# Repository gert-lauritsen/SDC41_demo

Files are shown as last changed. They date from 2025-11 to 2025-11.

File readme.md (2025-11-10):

# 🌿 SCD41_D_R2 Demo for ESP32-WROOM (Arduino)

Dette projekt demonstrerer, hvordan man bruger **Sensirion SCD41-D-R2** til at måle **CO₂**, **temperatur** og **relativ fugtighed** med et **ESP32-WROOM** udviklingsboard i **Arduino**.

## 🔌 Hardware (I²C forbindelse)
| SCD41 pin | ESP32 pin | Funktion |
|---|---|---|
| VDD | 3V3 | Forsyning |
| GND | GND | Jord |
| SDA | GPIO21 | I²C Data |
| SCL | GPIO22 | I²C Clock |

> Du kan vælge andre pins, men husk at ændre `Wire.begin(SDA, SCL)` i koden.

## 🧰 Software
- **Arduino IDE v2.x** eller **PlatformIO**
- **ESP32 by Espressif Systems** (Boards Manager)
- Bibliotek: **Sensirion I2C SCD4x** (Library Manager)

## 🚀 Kom i gang
1. Åbn mappen i Arduino IDE og vælg board **ESP32 Dev Module**.
2. Installer biblioteket **Sensirion I2C SCD4x**.
3. Tilslut sensoren som angivet ovenfor.
4. Upload `SCD41_ESP32_Arduino_Demo.ino` og åbn Serial Monitor @ **115200 baud**.
5. Skriv `h` + Enter for hjælpetekst/kommandoer.

## 🎛️ Seriel kommando-menu
- `h` — hjælp
- `start` / `stop` — start/stop måling
- `reinit` — software re-init
- `selftest` — kør intern selvtest
- `abc on` / `abc off` — Automatic Baseline Correction til/fra
- `alt <meter>` — sæt sensorhøjde, fx `alt 45`
- `press <mbar>` — sæt omgivende tryk, fx `press 1013`

## 🧪 Forventet output
```
SCD41-D-R2 Demo - ESP32-WROOM (Arduino)
I2C: SDA=21, SCL=22
Sensor SN: 1234-5678-9ABC
[OK] Measurement started
CO2: 413 ppm | Temp: 23.7 °C | RH: 44.6 %
...
```

## 📚 Referencer
- Sensirion SCD41-D-R2 datasheet
- Sensirion Arduino Library for SCD4x
- ESP32 Arduino Core Docs

## 👤 Forfatter
Gert Lauritsen — Fieldtest / Airborne Instruments

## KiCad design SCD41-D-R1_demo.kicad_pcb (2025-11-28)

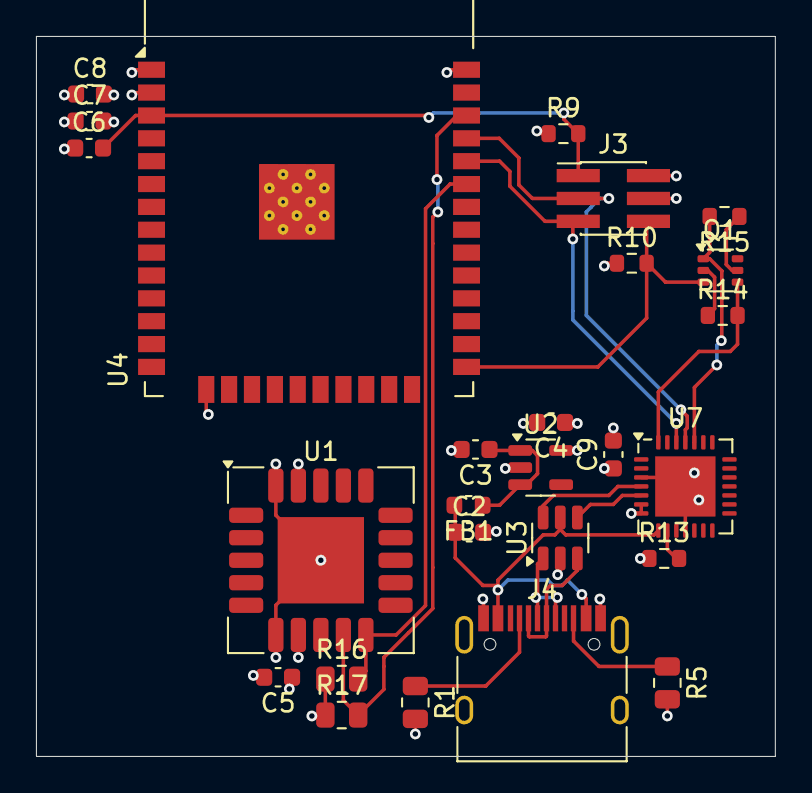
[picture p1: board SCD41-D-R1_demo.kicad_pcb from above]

Board: 4 copper layers, 41.1 x 40.0 mm, 26 parts (0 on the bottom side), 21 nets.

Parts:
C2: 10nF; C_0603_1608Metric
C3, C4, C5: 1uF; C_0603_1608Metric
C6, C7, C8: 0.1uf; C_0603_1608Metric
C9: 10u; C_0603_1608Metric
FB1: Ferrite Bead; L_0603_1608Metric
J3: Prog; PinHeader_2x03_P1.27mm_Vertical_SMD
J4: USB_C_Receptacle; USB_C_Receptacle_HRO_TYPE-C-31-M-12
Q1: BC846BS; SOT-363_SC-70-6
R1, R5: 5k1; R_0805_2012Metric
R9, R10: 10K; R_0603_1608Metric
R13: 1k; R_0603_1608Metric
R14, R15: 10k; R_0603_1608Metric
R16, R17: 10k; R_0805_2012Metric
U1: SCD41-D-R2; Sensirion_SCD4x-1EP_10.1x10.1mm_P1.25mm_EP4.8x4.8mm
U2: AP2112K-3.3; SOT-23-5
U3: USBLC6-2SC6; SOT-23-6
U4: ESP32-WROOM-32
U7: CP2102N-Axx-xQFN28; QFN-28-1EP_5x5mm_P0.5mm_EP3.35x3.35mm

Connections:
+3.3V: C4.1, C5.1, C7.2, C8.2, C9.1, J3.2, R9.1, R10.1, R13.1, R16.1, R17.1, U1.7 (VDD), U1.19 (VDD), U2.5 (VOUT), U4.2 (VDD), U7.6 (VDD), U7.7 (VREGIN)
BT: J3.6, Q1.3 (C2), R10.2, U4.25 (IO0)
D+: J4.A6 (D+), J4.B6 (D+), U3.1 (I/O1)
D-: J4.A7 (D-), J4.B7 (D-), U3.3 (I/O2)
EN: C6.2, J3.1, R9.2, U4.3 (EN)
GND: C2.2, C3.2, C4.2, C5.2, C6.1, C7.1, C8.1, C9.2, J3.4, J4.A1 (GND), J4.A12 (GND), J4.B1 (GND), J4.B12 (GND), J4.S1 (SHIELD), R1.2, R5.2, U1.6 (GND), U1.20 (GND), U1.21 (GND), U2.2 (GND), U3.2 (GND), U4.1 (GND), U4.15 (GND), U4.38 (GND), U4.39 (GND), U7.3 (GND), U7.11 (~SUSPEND), U7.29 (GND)
unnamed: J4.A5 (CC1), R1.1
unnamed: J4.B5 (CC2), R5.1
unnamed: Q1.2 (B1), R14.1
unnamed: Q1.1 (E1), R15.2, U7.24 (~RTS)
unnamed: Q1.5 (B2), R15.1
unnamed: Q1.4 (E2), R14.2, U7.28 (~DTR)
unnamed: C3.1, FB1.1, U2.1 (VIN), U2.3 (EN)
unnamed: R13.2, U7.9 (~RST)
RX: J3.5, U4.34 (RXD0/IO3), U7.26 (TXD)
SCL: R17.2, U1.9 (SCL), U4.36 (IO22)
SDA: R16.2, U1.10 (SDA), U4.33 (IO21)
TX: J3.3, U4.35 (TXD0/IO1), U7.25 (RXD)
USBN: U3.4 (I/O2), U7.5 (D-)
USBP: U3.6 (I/O1), U7.4 (D+)
VIN: C2.1, FB1.2, J4.A4 (VBUS), J4.A9 (VBUS), J4.B4 (VBUS), J4.B9 (VBUS), U3.5 (VBUS), U7.8 (VBUS)

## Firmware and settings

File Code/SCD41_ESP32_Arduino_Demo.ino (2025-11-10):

/*
  SCD41-D-R2 Demo for ESP32-WROOM (Arduino)
  - I2C pins: SDA=GPIO21, SCL=GPIO22
  - Serial: 115200 baud
  - Library: "Sensirion I2C SCD4x" (Library Manager)

  Serial commands (type and press Enter):
    h                   : help
    start               : start periodic measurement
    stop                : stop periodic measurement
    reinit              : software re-init of the sensor
    selftest            : run internal self-test
    abc on              : enable Automatic Baseline Correction
    abc off             : disable Automatic Baseline Correction
    alt <meters>        : set sensor altitude (ex: alt 45)
    press <mbar>        : set ambient pressure in mbar (ex: press 1013)
*/

#include <Wire.h>
#include <SensirionI2CScd4x.h>
#include <SensirionCore.h>  // for errorToString()

SensirionI2CScd4x scd4x;

static const int SDA_PIN = 21;
static const int SCL_PIN = 22;

const unsigned long MEAS_PERIOD_MS = 5000; // SCD41 updates ~every 5 s
unsigned long lastReadMs = 0;

// User settings (you can change defaults here)
bool abcEnabled = true;            // Automatic Baseline Correction
uint16_t altitudeMeters = 0;       // 0 = sea level
uint16_t pressureMbar = 0;         // 0 = not set (disabled)

void printErrorIfAny(uint16_t error, const char* context) {
  if (error) {
    char err[64];
    errorToString(error, err, sizeof(err));
    Serial.print("[ERR] ");
    Serial.print(context);
    Serial.print(": 0x");
    Serial.print(error, HEX);
    Serial.print(" -> ");
    Serial.println(err);
  }
}

void printHelp() {
  Serial.println();
  Serial.println(F("Commands:"));
  Serial.println(F("  h                 : help"));
  Serial.println(F("  start             : start periodic measurement"));
  Serial.println(F("  stop              : stop periodic measurement"));
  Serial.println(F("  reinit            : software re-init of the sensor"));
  Serial.println(F("  selftest          : run internal self-test"));
  Serial.println(F("  abc on/off        : enable/disable ABC"));
  Serial.println(F("  alt <meters>      : set altitude, ex: alt 45"));
  Serial.println(F("  press <mbar>      : set ambient pressure, ex: press 1013"));
  Serial.println();
}

void applyUserSettings() {
  uint16_t err;

  err = scd4x.setAutomaticSelfCalibration(abcEnabled);
  printErrorIfAny(err, "setAutomaticSelfCalibration");

  if (altitudeMeters > 0) {
    err = scd4x.setSensorAltitude(altitudeMeters);
    printErrorIfAny(err, "setSensorAltitude");
  }

  if (pressureMbar > 0) {
    err = scd4x.setAmbientPressure(pressureMbar);
    printErrorIfAny(err, "setAmbientPressure");
  }
}

void startMeasurement() {
  uint16_t err;

  // safety stop first
  err = scd4x.stopPeriodicMeasurement();
  if (!err) delay(50);

  // apply settings before start
  applyUserSettings();

  err = scd4x.startPeriodicMeasurement();
  if (err) {
    printErrorIfAny(err, "startPeriodicMeasurement");
  } else {
    Serial.println(F("[OK] Measurement started"));
  }
}

void stopMeasurement() {
  uint16_t err = scd4x.stopPeriodicMeasurement();
  if (err) {
    printErrorIfAny(err, "stopPeriodicMeasurement");
  } else {
    Serial.println(F("[OK] Measurement stopped"));
  }
}

void setup() {
  Serial.begin(115200);
  delay(200);
  Serial.println();
  Serial.println(F("SCD41-D-R2 Demo - ESP32-WROOM (Arduino)"));
  Serial.println(F("I2C: SDA=21, SCL=22"));
  Wire.begin(SDA_PIN, SCL_PIN);
  Wire.setClock(100000); // 100kHz is fine for SCD41

  scd4x.begin(Wire);

  // Read and show serial number (optional)
  uint16_t err;
  uint16_t serial0, serial1, serial2;
  err = scd4x.getSerialNumber(serial0, serial1, serial2);
  if (!err) {
    Serial.printf("Sensor SN: %04X-%04X-%04X\r\n", serial0, serial1, serial2);
  } else {
    printErrorIfAny(err, "getSerialNumber");
  }

  // Re-init (prepare sensor)
  err = scd4x.stopPeriodicMeasurement(); // if running
  printErrorIfAny(err, "stopPeriodicMeasurement");

  // (optional) Reinit sensor
  err = scd4x.reinit();
  if (!err) delay(20);
  printErrorIfAny(err, "reinit");

  // Apply defaults and start measurement
  startMeasurement();

  printHelp();
}

void handleSerial() {
  if (!Serial.available()) return;

  String line = Serial.readStringUntil('\n');
  line.trim();
  if (line.length() == 0) return;

  // to lower for easy parsing
  String cmd = line;
  cmd.toLowerCase();

  if (cmd == "h" || cmd == "help" || cmd == "?") {
    printHelp();
    return;
  }

  if (cmd == "start") {
    startMeasurement();
    return;
  }

  if (cmd == "stop") {
    stopMeasurement();
    return;
  }

  if (cmd == "reinit") {
    uint16_t err = scd4x.reinit();
    printErrorIfAny(err, "reinit");
    if (!err) {
      delay(20);
      Serial.println(F("[OK] reinit done"));
    }
    return;
  }

  if (cmd == "selftest") {
    uint16_t selfTestResult = 0;
    uint16_t err = scd4x.performSelfTest(selfTestResult);
    printErrorIfAny(err, "performSelfTest");
    if (!err) {
      if (selfTestResult == 0) {
        Serial.println(F("[OK] Self-test passed"));
      } else {
        Serial.print(F("[WARN] Self-test indicates issues: 0x"));
        Serial.println(selfTestResult, HEX);
      }
    }
    return;
  }

  if (cmd.startsWith("abc ")) {
    if (cmd.endsWith("on")) {
      abcEnabled = true;
      uint16_t err = scd4x.setAutomaticSelfCalibration(true);
      printErrorIfAny(err, "setAutomaticSelfCalibration(on)");
      if (!err) Serial.println(F("[OK] ABC ON"));
    } else if (cmd.endsWith("off")) {
      abcEnabled = false;
      uint16_t err = scd4x.setAutomaticSelfCalibration(false);
      printErrorIfAny(err, "setAutomaticSelfCalibration(off)");
      if (!err) Serial.println(F("[OK] ABC OFF"));
    } else {
      Serial.println(F("[ERR] Usage: abc on | abc off"));
    }
    return;
  }

  if (cmd.startsWith("alt ")) {
    int value = cmd.substring(4).toInt();
    if (value < 0) value = 0;
    altitudeMeters = (uint16_t)value;
    uint16_t err = scd4x.setSensorAltitude(altitudeMeters);
    printErrorIfAny(err, "setSensorAltitude");
    if (!err) {
      Serial.print(F("[OK] Altitude set to "));
      Serial.print(altitudeMeters);
      Serial.println(F(" m"));
    }
    return;
  }

  if (cmd.startsWith("press ")) {
    int value = cmd.substring(6).toInt();
    if (value < 0) value = 0;
    pressureMbar = (uint16_t)value;
    uint16_t err = scd4x.setAmbientPressure(pressureMbar);
    printErrorIfAny(err, "setAmbientPressure");
    if (!err) {
      Serial.print(F("[OK] Ambient pressure set to "));
      Serial.print(pressureMbar);
      Serial.println(F(" mbar"));
    }
    return;
  }

  Serial.println(F("[ERR] Unknown command. Type 'h' for help."));
}

void readAndPrintMeasurement() {
  uint16_t co2;
  float temp;
  float rh;

  uint16_t err = scd4x.readMeasurement(co2, temp, rh);
  if (err) {
    printErrorIfAny(err, "readMeasurement");
    return;
  }

  // co2==0 indicates no new data yet
  if (co2 == 0) {
    return;
  }

  Serial.print(F("CO2: "));
  Serial.print(co2);
  Serial.print(F(" ppm | Temp: "));
  Serial.print(temp, 1);
  Serial.print(F(" °C | RH: "));
  Serial.print(rh, 1);
  Serial.println(F(" %"));
}

void loop() {
  handleSerial();

  unsigned long now = millis();
  if (now - lastReadMs >= MEAS_PERIOD_MS) {
    lastReadMs = now;
    readAndPrintMeasurement();
  }
}
